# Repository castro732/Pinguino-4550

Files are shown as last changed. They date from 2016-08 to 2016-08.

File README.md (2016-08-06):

#Pingüino 4550

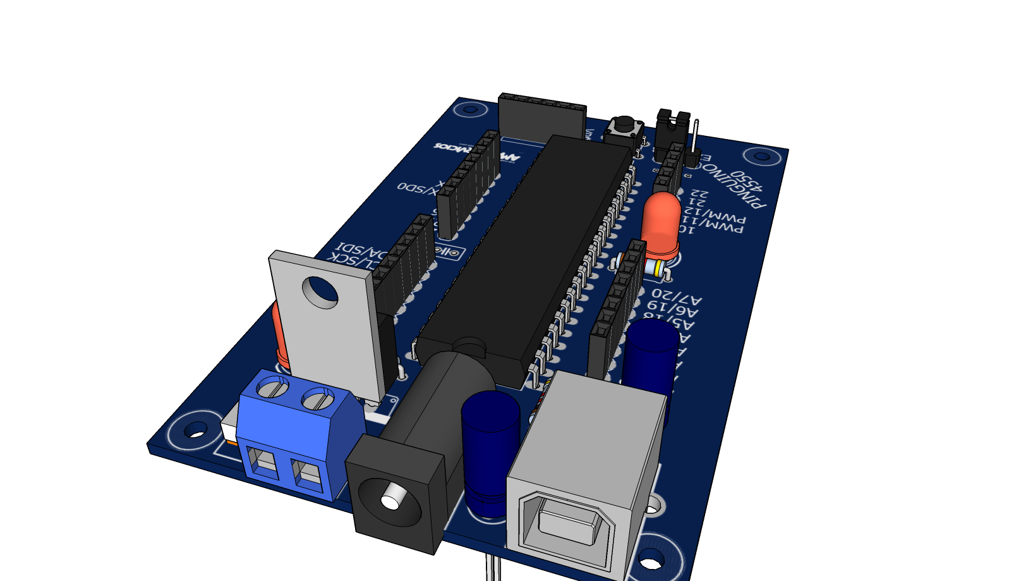
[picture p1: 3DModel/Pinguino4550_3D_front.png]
3D Top View


## Description

Board for a Pingüino with a PIC 18F4550.

##Features
- USB type B input.
- Jumper selector for power supply (USB or External).
	- External input provides a PowerJack or a Screw Terminal.
	- External input must be between 7V and 12V.
- ICSP input for programming directly to the PIC using a PICKit2 (useful for uploading the bootloader).
- Reset button.
- Power and User LEDs.
- Mounting holes.
- Small form factor, ~9cm x ~6cm

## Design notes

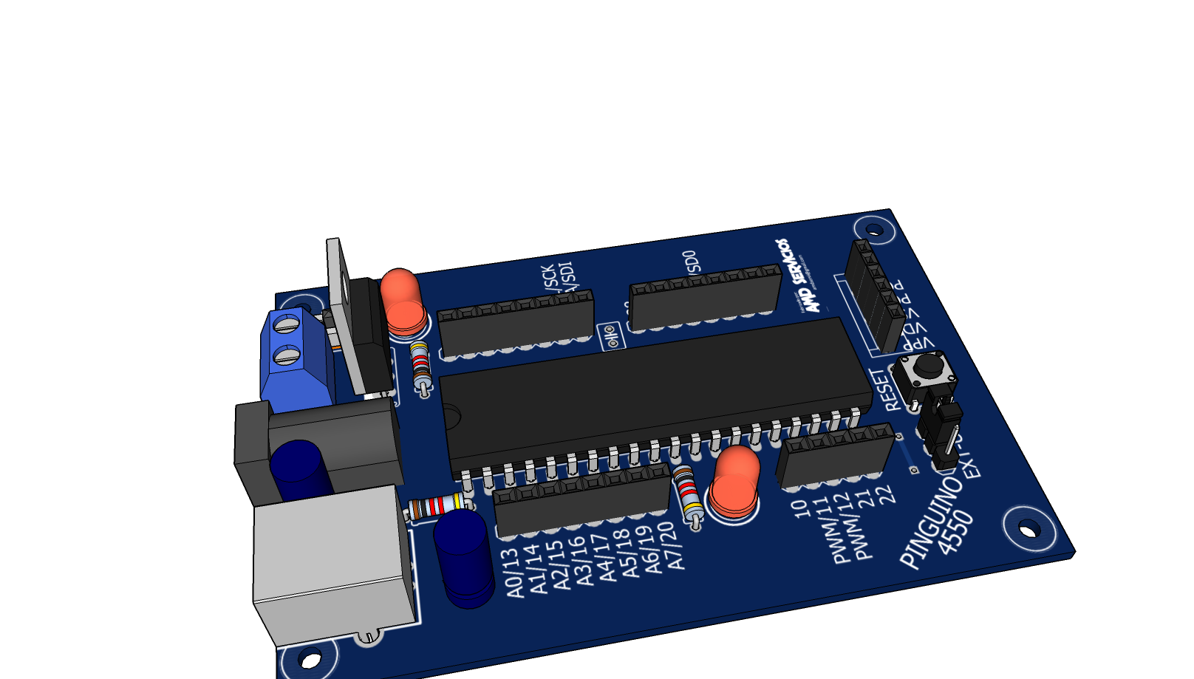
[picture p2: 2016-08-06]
3DModel/Pinguino4550_3D_angle2.png

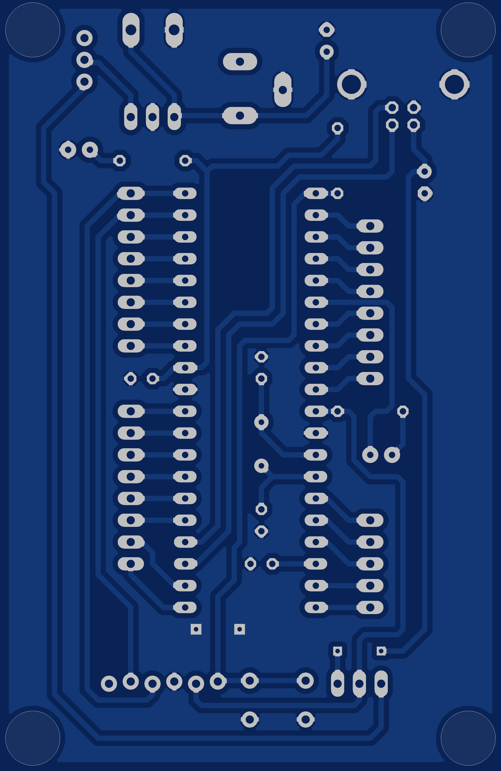
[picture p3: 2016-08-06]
3DModel/eagleUp_Pinguino4550_board_bottom.png

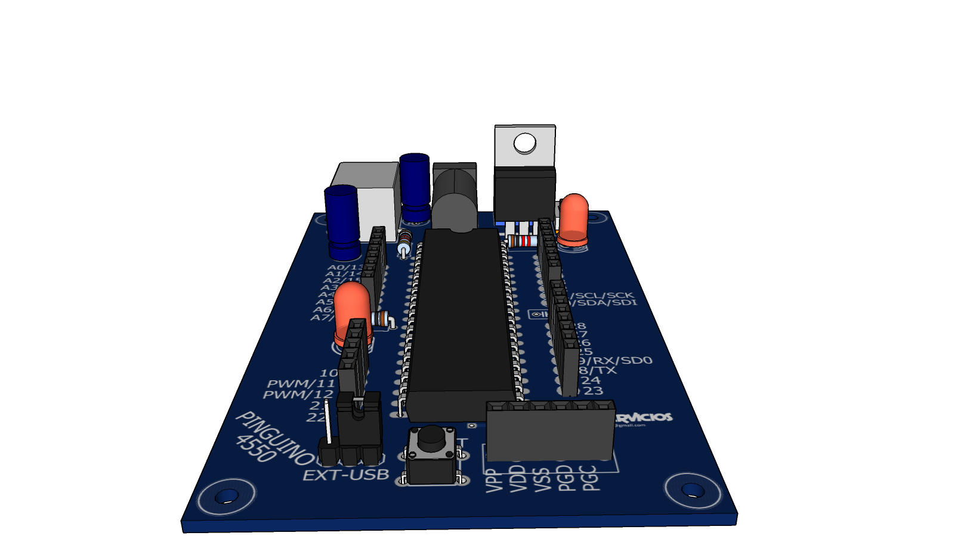
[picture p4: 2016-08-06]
3DModel/Pinguino4550_3D_back.png

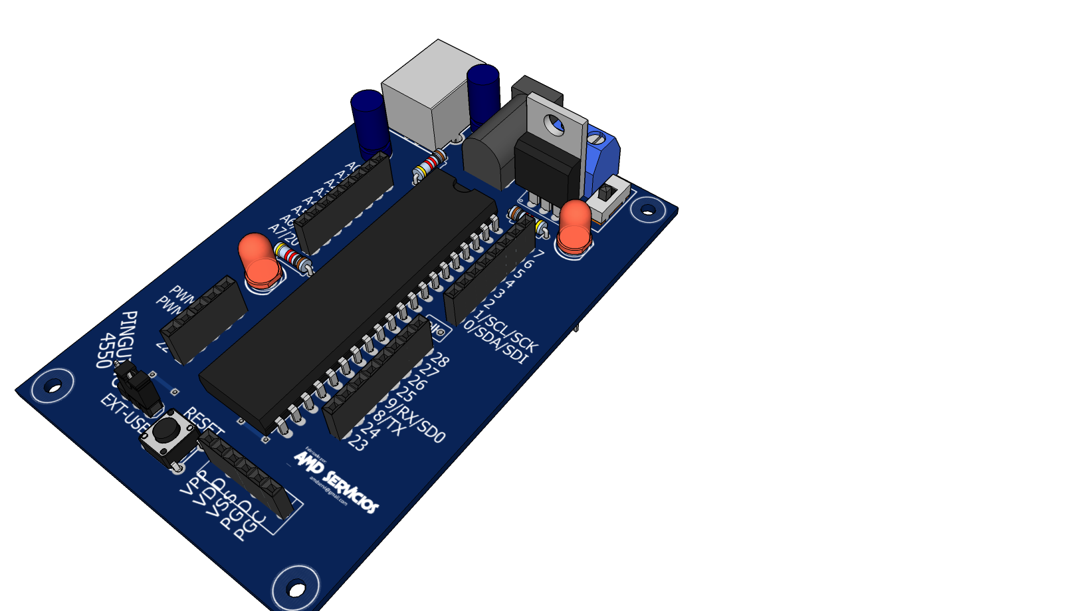
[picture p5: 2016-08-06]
3DModel/Pinguino4550_3D_angle.png

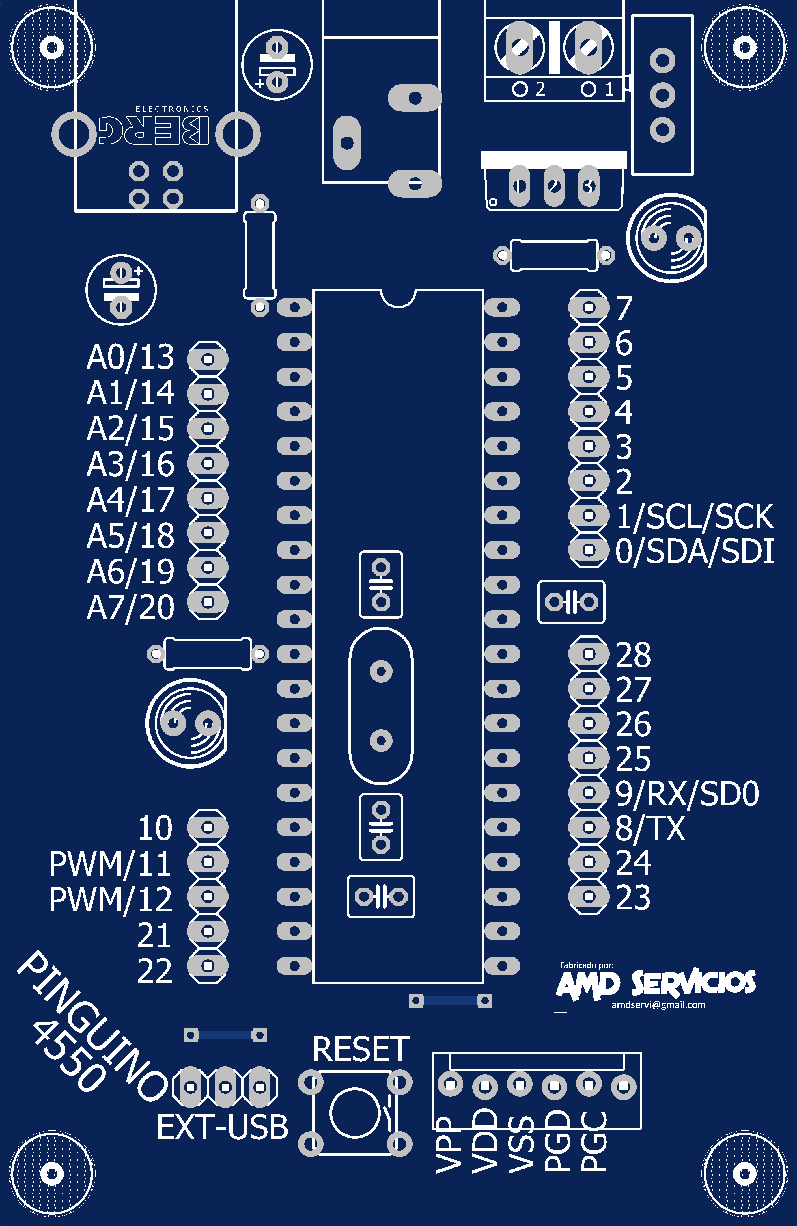
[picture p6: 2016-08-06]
3DModel/eagleUp_Pinguino4550_board_top.png

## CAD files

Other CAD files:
3DModel/Pinguino4550.skp

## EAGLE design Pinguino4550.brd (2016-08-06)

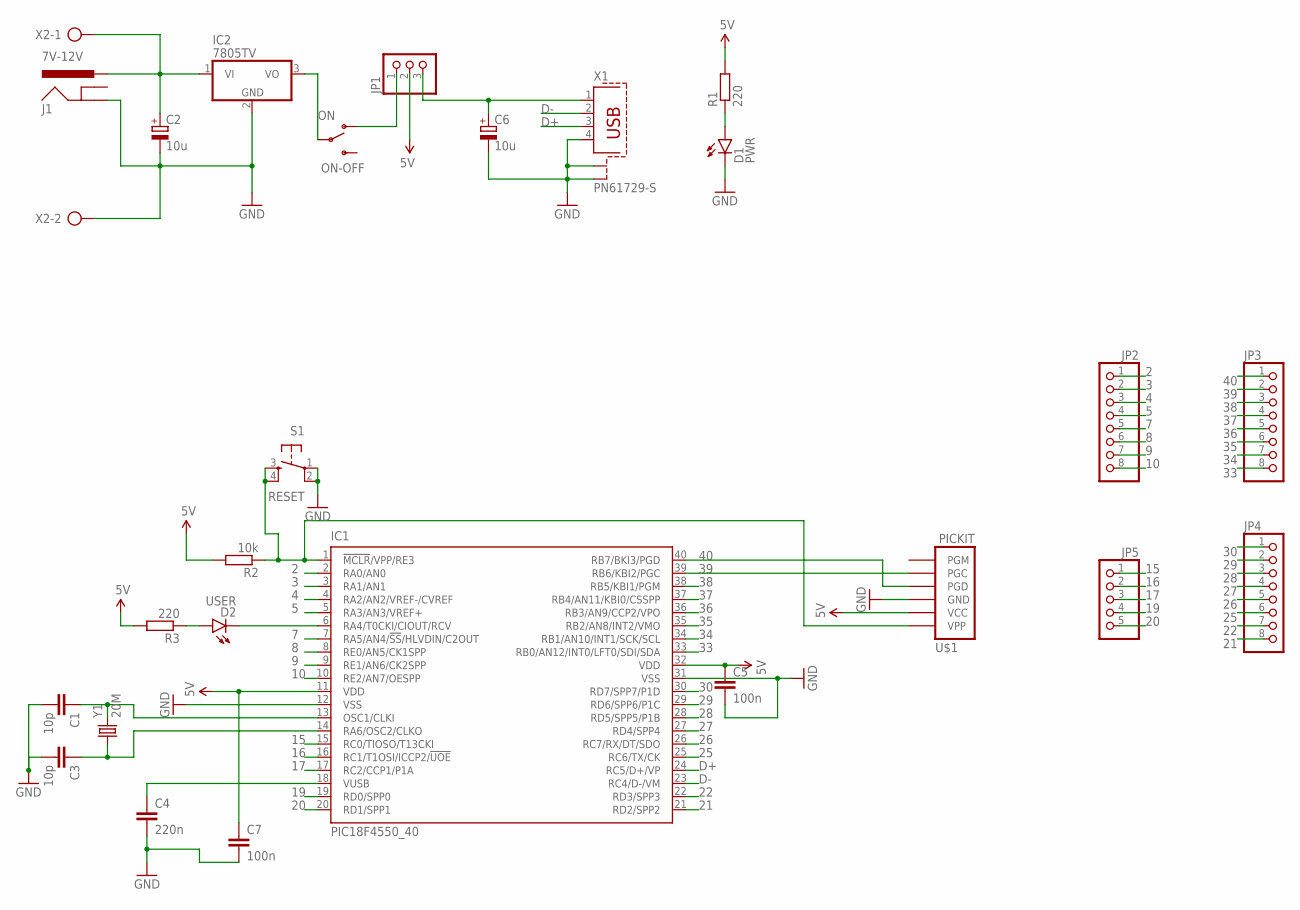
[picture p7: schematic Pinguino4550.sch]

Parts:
C1, C3: 10p; C025-030X050
C2, C6: 10u; E2,5-5
C4: 220n; C025-030X050
C5, C7: 100n; C025-030X050
D1: PWR; LED5MM
D2: USER; LED5MM
IC1: PIC18F4550_40; DIL40
IC2: 7805TV; TO220V
J1: 7V-12V; POWER_JACK_SLOT
JP1: PINHD-1X3; 1X03
JP2, JP3, JP4: PINHD-1X8; 1X08
JP5: PINHD-1X5; 1X05
ON-OFF: ON; SWITCH-SPDT
R1, R3: 220; 0207/7
R2: 10k; 0207/7
S1: RESET; TACTILE-PTH
U$1: PICKIT; MOLEX-1X6_LOCK
X1: PN61729-S
X2: AK500/2
Y1: 20M; HC49US

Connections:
2: IC1.2 (RA0/AN0), JP2.1
3: IC1.3 (RA1/AN1), JP2.2
4: IC1.4 (RA2/AN2/VREF-/CVREF), JP2.3
5: IC1.5 (RA3/AN3/VREF+), JP2.4
5V: C5.1, C7.1, IC1.11 (VDD), IC1.32 (VDD), JP1.2, R1.2, R2.2, R3.2, U$1.5 (VCC)
7: IC1.7 (RA5/AN4/!SS!/HLVDIN/C2OUT), JP2.5
8: IC1.8 (RE0/AN5/CK1SPP), JP2.6
9: IC1.9 (RE1/AN6/CK2SPP), JP2.7
10: IC1.10 (RE2/AN7/OESPP), JP2.8
15: IC1.15 (RC0/TIOSO/T13CKI), JP5.1
16: IC1.16 (RC1/T1OSI/ICCP2/!UOE), JP5.2
17: IC1.17 (RC2/CCP1/P1A), JP5.3
19: IC1.19 (RD0/SPP0), JP5.4
20: IC1.20 (RD1/SPP1), JP5.5
21: IC1.21 (RD2/SPP2), JP4.8
22: IC1.22 (RD3/SPP3), JP4.7
25: IC1.25 (RC6/TX/CK), JP4.6
26: IC1.26 (RC7/RX/DT/SDO), JP4.5
27: IC1.27 (RD4/SPP4), JP4.4
28: IC1.28 (RD5/SPP5/P1B), JP4.3
29: IC1.29 (RD6/SPP6/P1C), JP4.2
30: IC1.30 (RD7/SPP7/P1D), JP4.1
33: IC1.33 (RB0/AN12/INT0/LFT0/SDI/SDA), JP3.8
34: IC1.34 (RB1/AN10/INT1/SCK/SCL), JP3.7
35: IC1.35 (RB2/AN8/INT2/VMO), JP3.6
36: IC1.36 (RB3/AN9/CCP2/VPO), JP3.5
37: IC1.37 (RB4/AN11/KBI0/CSSPP), JP3.4
38: IC1.38 (RB5/KBI1/PGM), JP3.3
39: IC1.39 (RB6/KBI2/PGC), JP3.2, U$1.2 (PGC)
40: IC1.40 (RB7/BKI3/PGD), JP3.1, U$1.3 (PGD)
D+: IC1.24 (RC5/D+/VP), X1.3
D-: IC1.23 (RC4/D-/VM), X1.2
GND: C1.2, C2.-, C3.2, C4.2, C5.2, C6.-, C7.2, D1.K (C), IC1.12 (VSS), IC1.31 (VSS), IC2.2 (GND), J1.GND@2 (GND), S1.1, S1.2, U$1.4 (GND), X1.4, X1.S1, X1.S2, X2.2
unnamed: C2.+, IC2.1 (VI), J1.PWR, X2.1
unnamed: D1.A, R1.1
unnamed: IC2.3 (VO), ON-OFF.2
unnamed: JP1.1, ON-OFF.1 (O)
unnamed: C1.1, IC1.13 (OSC1/CLKI), Y1.2
unnamed: C6.+, JP1.3, X1.1
unnamed: C3.1, IC1.14 (RA6/OSC2/CLKO), Y1.1
unnamed: IC1.1 (!MCLR!/VPP/RE3), R2.1, S1.3, S1.4, U$1.6 (VPP)
unnamed: D2.K (C), IC1.6 (RA4/T0CKI/CIOUT/RCV)
unnamed: D2.A, R3.1
unnamed: C4.1, IC1.18 (VUSB)

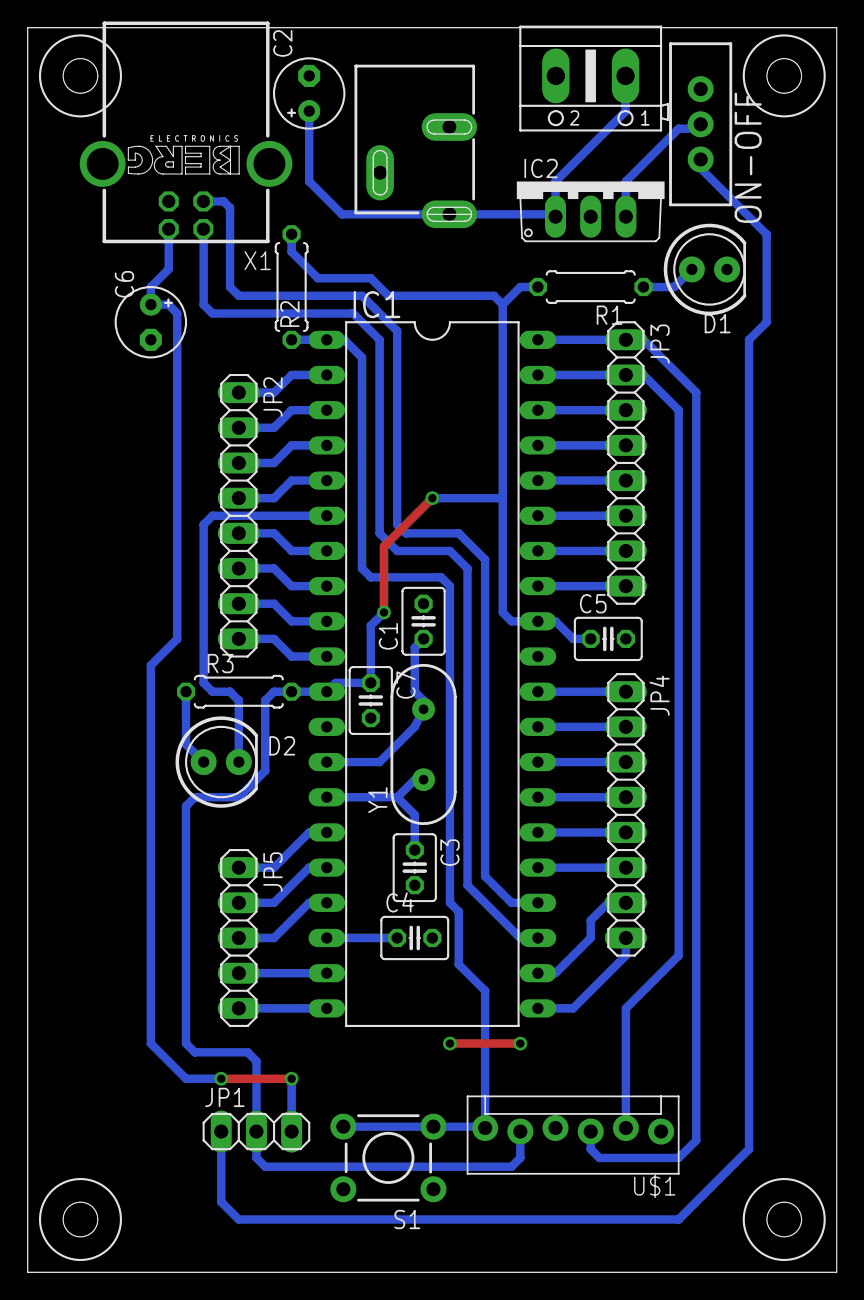
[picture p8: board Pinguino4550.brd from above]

Board: 2 copper layers, 58.4 x 89.8 mm, 30 parts (0 on the bottom side), 44 nets.

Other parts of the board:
U$2, U$4, U$5, U$6: DRIL-2,5

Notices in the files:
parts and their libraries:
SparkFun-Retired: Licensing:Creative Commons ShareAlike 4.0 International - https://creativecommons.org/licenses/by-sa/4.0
